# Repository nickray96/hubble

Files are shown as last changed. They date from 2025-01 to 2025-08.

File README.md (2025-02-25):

# hubble
A switched USB hub. 

# Rev 1.0:
* USB 2.0 and USB 3.0
* Tested working (see errata)
* Toggle SW1 to select between host 1 and 2
* Debug connector provides I2C to use via TotalPhase Aardvark (or other debug device)
  * Also routed to USB-C SBU

## Errata
* USB5744 does not enter runtime, looks for I2C host. Remove R14 and R17, puts hub in headless mode.

# Rev 2.0:
* Enable USB5744 port power toggling
* Optionally drive mux sel via Raspberry Pi Pico W (useful for home automation)
* Add DisplayPort mux so I can stop using my monitor OSD (TBD which connectors I'll use)

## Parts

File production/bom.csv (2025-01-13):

Designator | Footprint | Quantity | Value | LCSC Part #
C1, C10, C11, C12, C14, C15, C16, C17, C18, C19, C20, C21, C22, C23, C24, C25, C27, C28, C29, C30, C31, C32, C34, C35, C37, C38, C39, C40, C41, C42, C43, C44, C6, C7, C8, C9 | 0603 | 36 | 0.1uF
C13, C33 | 0603 | 2 | 10uF
C2, C45, C46, C47, C48 | 0603 | 5 | 2.2uF
C26, C36 | 0603 | 2 | 22uF
C3, C4 | 0603 | 2 | 20pF
J1, J2, J5, J6, J7, J8 | USB-TH_XUNPU_USB-301WD-ARY | 6 | USB3_A_LCSC | C2895025
J3 | USB_C_CONN_105450-0101_MOLEX | 1 | USB_C_Receptacle_Molex | C134092
J9 | PinHeader_2x02_P2.54mm_Vertical | 1 | Conn_02x02_Odd_Even
R1 | 0603 | 1 | 330
R10, R13, R14, R17 | 0603 | 4 | 10k
R15 | 0603 | 1 | 11.8k
R16 | 0603 | 1 | 3.74k
R18, R24, R7 | 0603 | 3 | 50k
R19 | 0603 | 1 | 12k
R2, R3 | 0603 | 2 | 5.1k
R20, R21 | 0603 | 2 | 200k
R22 | 0603 | 1 | 12.4k
R23 | 0603 | 1 | 24.9k
R4, R5 | 0603 | 2 | 0
R8 | 0603 | 1 | 100k
SW1 | SW-TH_K3-2235D-F1 | 1 | K3-2235D-F1 | C189615
TP1, TP2, TP3, TP4, TP5, TP6, TP7 | TestPoint_Pad_1.0x1.0mm | 7 | TestPoint
U1 | SOT-143 | 1 | MAX6816EUS+T | C41637
U10, U11, U12, U13, U2, U8, U9 | Texas_DPY0002A_0.6x1mm_P0.65mm | 7 | TPD1E05U06DPY | C2937017
U3 | UQFN-10 | 1 | TS3USB221RSER | C130085
U4, U6 | RGR20_2P05X2P05_TEX | 2 | TPS7A5201QRGRRQ1 | C523802
U5 | VQFN56_2G_MCH | 1 | USB5744 | C633621
U7 | TMLP-18_L2.8-W2.0-P0.40-BL-EP | 1 | FUSB340
Y1 | Crystal_SMD_3225-4Pin_3.2x2.5mm | 1 | X322525MOB4SI | C9006

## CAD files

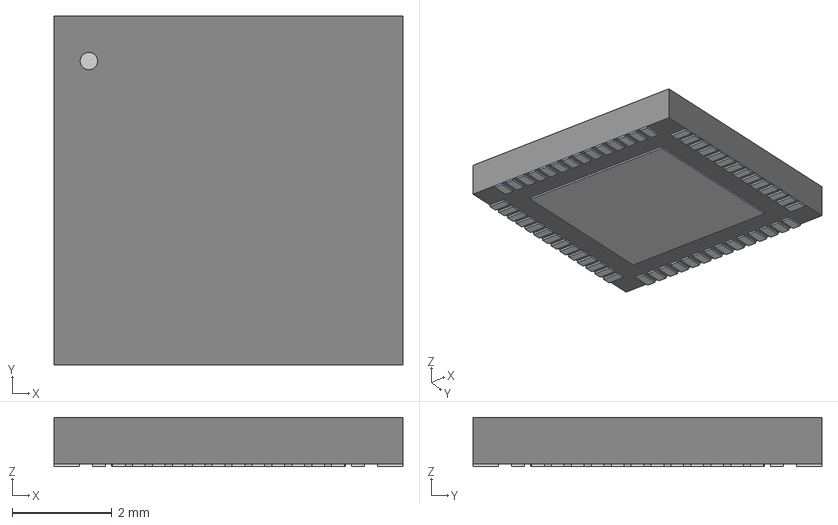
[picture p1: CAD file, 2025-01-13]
3d/VQFN56_2G_MCH.step
7.01 x 7.01 x 0.993 mm

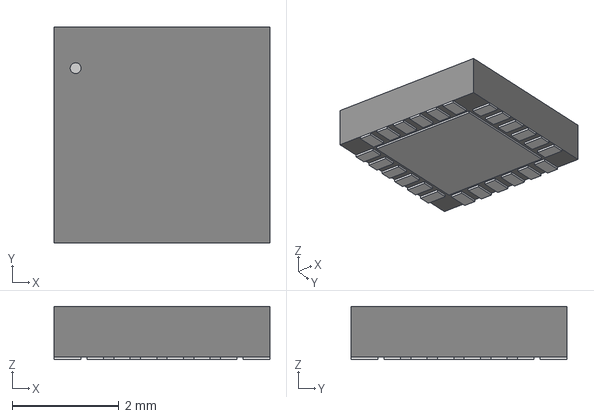
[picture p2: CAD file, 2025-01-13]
3d/QFN24EP_4X4_STM.step
4.04 x 4.04 x 0.993 mm

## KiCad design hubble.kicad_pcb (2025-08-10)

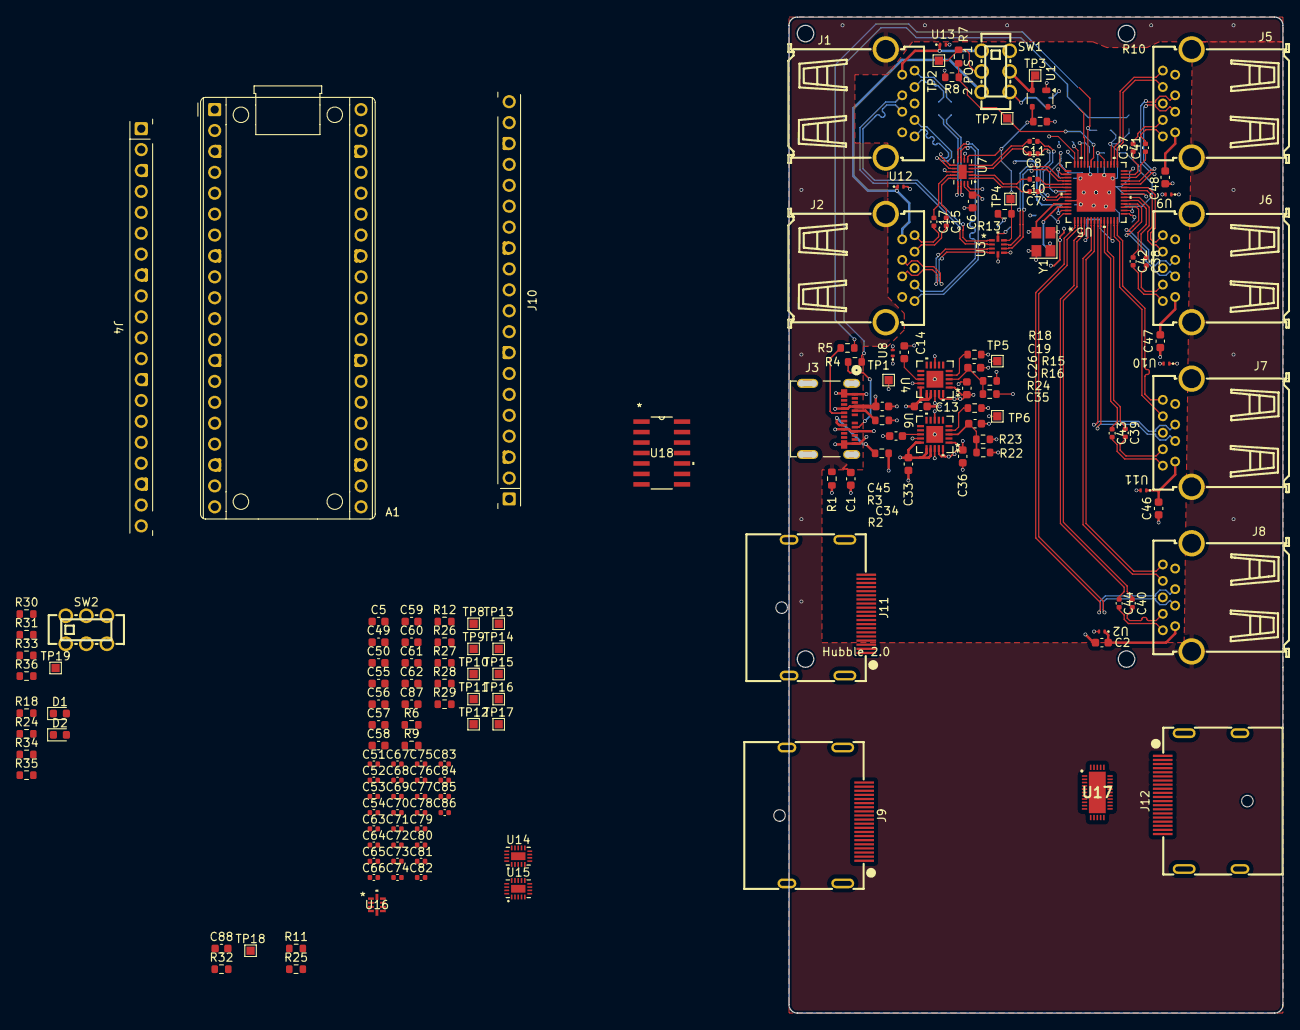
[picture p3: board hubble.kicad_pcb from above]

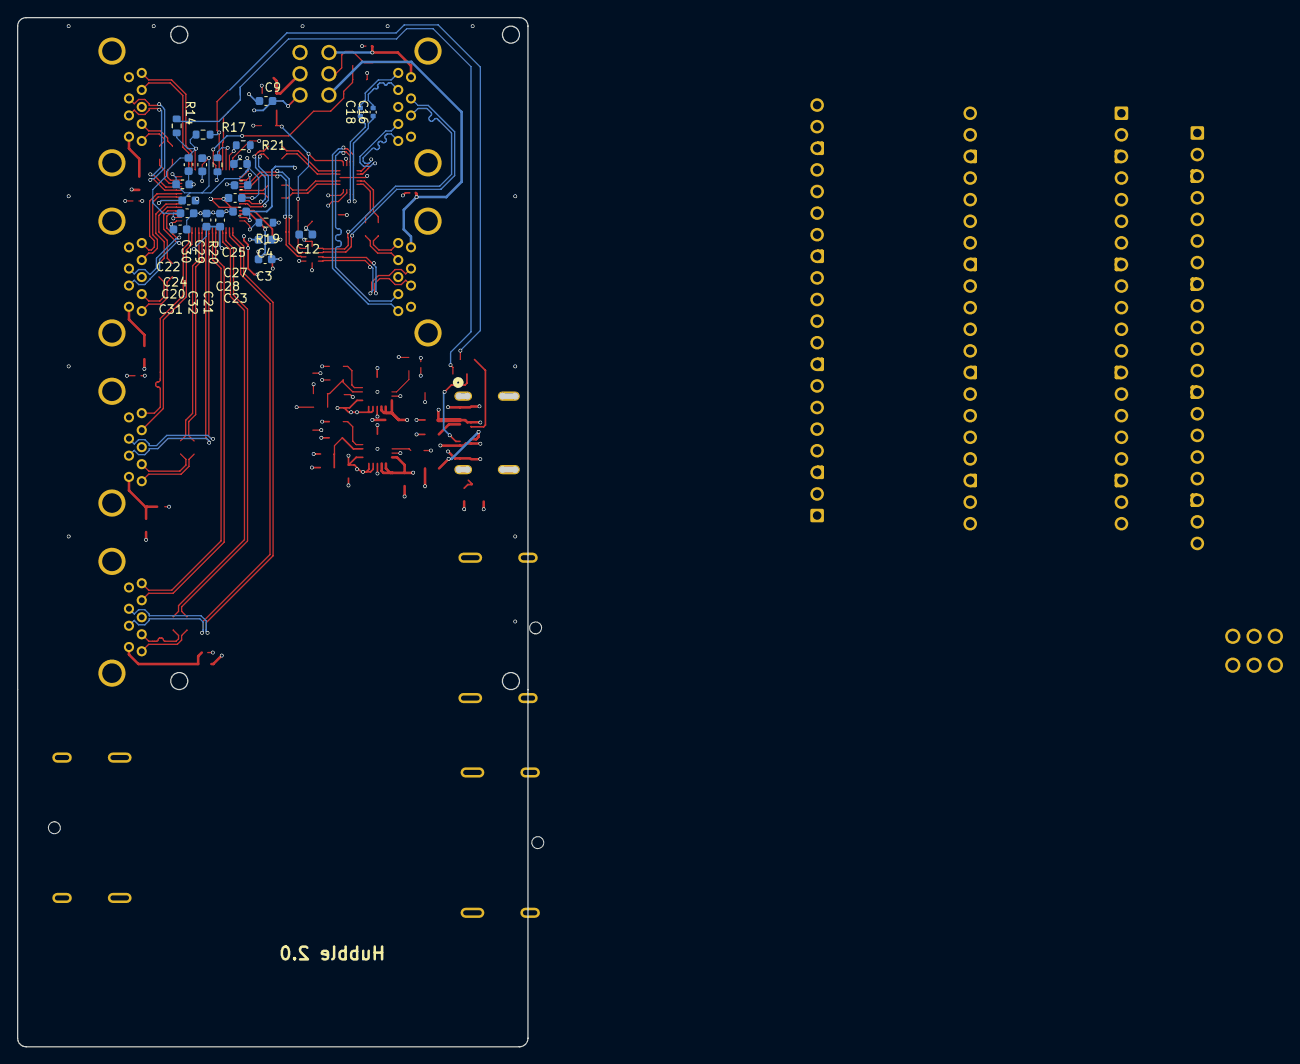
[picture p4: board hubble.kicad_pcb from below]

Board: 4 copper layers, 61.9 x 121.0 mm, 181 parts (23 on the bottom side), 181 nets.

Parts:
A1: RaspberryPi_Pico_W; RaspberryPi_Pico_Common_THT
C1, C5, C6, C9, C12, C14, C19, C20, C21, C22, C23, C24, C25, C27, C28, C29, C30, C31, C32, C34, C35, C49, C50, C55, C56, C57, C58, C59, C60, C61, C87, C88: 0.1uF; C_0603_1608Metric
C2, C45, C46, C47, C48: 2.2uF; C_0603_1608Metric
C3, C4: 20pF; C_0603_1608Metric
C7, C8, C10, C11, C15, C16, C17, C18, C37, C38, C39, C40, C41, C42, C43, C44, C51, C52, C53, C54, C63, C64, C65, C66, C67, C68, C69, C70, C71, C72, C73, C74, C75, C76, C77, C78, C79, C80, C81, C82, C83, C84, C85, C86: 0.1uF; C_0402_1005Metric
C13, C33: 10uF; C_0603_1608Metric
C26, C36: 22uF; C_0603_1608Metric
C62: 4.7uF; C_0603_1608Metric
D1, D2: LED_green; LED_0603_1608Metric
J1, J2, J5, J6, J7, J8: USB3_A_LCSC; USB-TH_XUNPU_USB-301WD-ARY
J3: USB_C_Receptacle_Molex; USB_C_CONN_105450-0101_MOLEX
J4: Pico_Socket_A; RaspberryPi_Pico_PinSocket_1x20_P2.54mm_Vertical
J9, J11, J12: DisplayPort; DISPLAYPORT_XDPF-0205-20S
J10: Pico_Socket_B; RaspberryPi_Pico_PinSocket_1x20_P2.54mm_Vertical
R1, R6, R9, R24#2, R29, R35: 330; R_0603_1608Metric
R2, R3: 5.1k; R_0603_1608Metric
R4, R5, R11, R25: 0; R_0603_1608Metric
R7, R18, R24: 50k; R_0603_1608Metric
R8: 100k; R_0603_1608Metric
R10, R13, R14, R17, R18#2, R26, R27, R30, R32, R34, R36: 10k; R_0603_1608Metric
R12, R28: 1M; R_0603_1608Metric
R15: 11.8k; R_0603_1608Metric
R16: 3.74k; R_0603_1608Metric
R19: 12k; R_0603_1608Metric
R20, R21: 200k; R_0603_1608Metric
R22: 12.4k; R_0603_1608Metric
R23: 24.9k; R_0603_1608Metric
R31, R33: 27; R_0603_1608Metric
SW1, SW2: K3-2235D-F1; SW-TH_K3-2235D-F1
TP1, TP2, TP3, TP4, TP5, TP6, TP7, TP8, TP9, TP10, TP11, TP12, TP13, TP14, TP15, TP16, TP17, TP18, TP19: TestPoint; TestPoint_Pad_1.0x1.0mm
U1: MAX6816EUS+T; SOT-143
U2, U8, U9, U10, U11, U12, U13: TPD1E05U06DPY; Texas_DPY0002A_0.6x1mm_P0.65mm
U3, U16: TS3USB221RSER; UQFN-10
U4, U6: TPS7A5201QRGRRQ1; RGR20_2P05X2P05_TEX
U5: USB5744; VQFN56_2G_MCH
U7, U14, U15: FUSB340; TMLP-18_L2.8-W2.0-P0.40-BL-EP
U17: PI3DPX1203BZLEX; QFN40P300X600X80-33N
U18: SN74CBTLV3126DR; D14
Y1: X322525MOB4SI; Crystal_SMD_3225-4Pin_3.2x2.5mm

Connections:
/DisplayPort/DP_HOST0_AUX_N: C54.2, U16.2 (1D-)
/DisplayPort/DP_HOST0_AUX_P: C51.2, U16.1 (1D+)
/DisplayPort/DP_HOST0_D0_N: C64.1, J9.3 (D0_N)
/DisplayPort/DP_HOST0_D0_P: C63.1, J9.1 (D0_P)
/DisplayPort/DP_HOST0_D1_N: C66.1, J9.6 (D1_N)
/DisplayPort/DP_HOST0_D1_P: C65.1, J9.4 (D1_P)
/DisplayPort/DP_HOST0_D2_N: C68.1, J9.9 (D2_N)
/DisplayPort/DP_HOST0_D2_P: C67.1, J9.7 (D2_P)
/DisplayPort/DP_HOST0_D3_N: C70.1, J9.12 (D3_N)
/DisplayPort/DP_HOST0_D3_P: C69.1, J9.10 (D3_P)
/DisplayPort/DP_HOST0_HPD: J9.18 (HPD), U18.2 (1A)
/DisplayPort/DP_HOST1_AUX_N: C53.2, U16.4 (2D-)
/DisplayPort/DP_HOST1_AUX_P: C52.2, U16.3 (2D+)
/DisplayPort/DP_HOST1_D0_N: C81.1, J11.3 (D0_N)
/DisplayPort/DP_HOST1_D0_P: C79.1, J11.1 (D0_P)
/DisplayPort/DP_HOST1_D1_N: C85.1, J11.6 (D1_N)
/DisplayPort/DP_HOST1_D1_P: C83.1, J11.4 (D1_P)
/DisplayPort/DP_HOST1_D2_N: C82.1, J11.9 (D2_N)
/DisplayPort/DP_HOST1_D2_P: C80.1, J11.7 (D2_P)
/DisplayPort/DP_HOST1_D3_N: C86.1, J11.12 (D3_N)
/DisplayPort/DP_HOST1_D3_P: C84.1, J11.10 (D3_P)
/DisplayPort/DP_HOST1_HPD: J11.18 (HPD), U18.5 (2A)
/DisplayPort/DP_SINK_AUX_N: J12.17 (AUX_N), U16.7 (D-)
/DisplayPort/DP_SINK_AUX_P: J12.15 (AUX_P), U16.8 (D+)
/DisplayPort/DP_SINK_HPD: J12.18 (HPD), U18.3 (1B), U18.6 (2B)
/DisplayPort/I2C_SCL: J4.5 (GPIO3), R5.2, R11.1, R14.2, U17.13 (SCL)
/DisplayPort/I2C_SDA: J4.4 (GPIO2), R4.2, R17.2, R25.1, U17.12 (SDA)
/DisplayPort/MUX_SEL: R10.1, R13.1, TP4.1, U1.3 (OUT), U3.9 (S), U7.6 (S), U14.6 (S), U15.6 (S), U16.9 (S), U18.4 (2OE)
/DisplayPort/~DP_RST: R27.1, U17.29 (FG1/I2C_RESET#)
/DisplayPort/~MUX_SEL: R32.1, TP18.1, U18.1 (1OE)
/Hub/DEVICE_1_USB_N: J8.2 (D-), U5.2 (USB2DN_DM1/PRT_DIS_M1)
/Hub/DEVICE_1_USB_P: J8.3 (D+), U5.1 (USB2DN_DP1/PRT_DIS_P1)
/Hub/DEVICE_2_USB_N: J7.2 (D-), U5.9 (USB2DN_DM2/PRT_DIS_M2)
/Hub/DEVICE_2_USB_P: J7.3 (D+), U5.8 (USB2DN_DP2/PRT_DIS_P2)
/Hub/DEVICE_3_USB_N: J6.2 (D-), U5.18 (USB2DN_DM3/PRT_DIS_M3)
/Hub/DEVICE_3_USB_P: J6.3 (D+), U5.17 (USB2DN_DP3/PRT_DIS_P3)
/Hub/DEVICE_4_USB_N: J5.2 (D-), U5.25 (USB2DN_DM4/PRT_DIS_M4)
/Hub/DEVICE_4_USB_P: J5.3 (D+), U5.24 (USB2DN_DP4/PRT_DIS_P4)
/Hub/HOST_1_USB_N: J1.2 (D-), U3.2 (1D-)
/Hub/HOST_1_USB_P: J1.3 (D+), U3.1 (1D+)
/Hub/HOST_2_USB_N: J2.2 (D-), U3.4 (2D-)
/Hub/HOST_2_USB_P: J2.3 (D+), U3.3 (2D+)
/Hub/HUB_USB_N: U3.7 (D-), U5.46 (USB2UP_DM)
/Hub/HUB_USB_P: U3.8 (D+), U5.45 (USB2UP_DP)
/Hub/SS_RX_DEVICE_1_N: J8.5 (SSRX-), U5.7 (USB3DN_RXDM1)
/Hub/SS_RX_DEVICE_1_P: J8.6 (SSRX+), U5.6 (USB3DN_RXDP1)
/Hub/SS_RX_DEVICE_2_N: J7.5 (SSRX-), U5.14 (USB3DN_RXDM2)
/Hub/SS_RX_DEVICE_2_P: J7.6 (SSRX+), U5.13 (USB3DN_RXDP2)
/Hub/SS_RX_DEVICE_3_N: J6.5 (SSRX-), U5.23 (USB3DN_RXDM3)
/Hub/SS_RX_DEVICE_3_P: J6.6 (SSRX+), U5.22 (USB3DN_RXDP3)
/Hub/SS_RX_DEVICE_4_N: J5.5 (SSRX-), U5.30 (USB3DN_RXDM4)
/Hub/SS_RX_DEVICE_4_P: J5.6 (SSRX+), U5.29 (USB3DN_RXDP4)
/Hub/SS_RX_HOST_1_N: J1.5 (SSRX-), U7.10 (SSRX1+)
/Hub/SS_RX_HOST_1_P: J1.6 (SSRX+), U7.11 (SSRX1-)
/Hub/SS_RX_HOST_2_N: J2.5 (SSRX-), U7.9 (SSRX2-)
/Hub/SS_RX_HOST_2_P: J2.6 (SSRX+), U7.8 (SSRX2+)
/Hub/SS_RX_HUB_CAP_N: C8.1, U7.4 (SSRXCOM-)
/Hub/SS_RX_HUB_CAP_P: C7.1, U7.5 (SSRXCOM+)
/Hub/SS_RX_HUB_N: C8.2, U5.51 (USB3UP_RXDM)
/Hub/SS_RX_HUB_P: C7.2, U5.50 (USB3UP_RXDP)
/Hub/SS_TX_DEVICE_1_CAP_N: C40.1, U5.4 (USB3DN_TXDM1)
/Hub/SS_TX_DEVICE_1_CAP_P: C44.1, U5.3 (USB3DN_TXDP1)
/Hub/SS_TX_DEVICE_1_N: C40.2, J8.8 (SSTX-)
/Hub/SS_TX_DEVICE_1_P: C44.2, J8.9 (SSTX+)
/Hub/SS_TX_DEVICE_2_CAP_N: C39.1, U5.11 (USB3DN_TXDM2)
/Hub/SS_TX_DEVICE_2_CAP_P: C43.1, U5.10 (USB3DN_TXDP2)
/Hub/SS_TX_DEVICE_2_N: C39.2, J7.8 (SSTX-)
/Hub/SS_TX_DEVICE_2_P: C43.2, J7.9 (SSTX+)
/Hub/SS_TX_DEVICE_3_CAP_N: C38.1, U5.20 (USB3DN_TXDM3)
/Hub/SS_TX_DEVICE_3_CAP_P: C42.1, U5.19 (USB3DN_TXDP3)
/Hub/SS_TX_DEVICE_3_N: C38.2, J6.8 (SSTX-)
/Hub/SS_TX_DEVICE_3_P: C42.2, J6.9 (SSTX+)
/Hub/SS_TX_DEVICE_4_CAP_N: C37.1, U5.27 (USB3DN_TXDM4)
/Hub/SS_TX_DEVICE_4_CAP_P: C41.1, U5.26 (USB3DN_TXDP4)
/Hub/SS_TX_DEVICE_4_N: C37.2, J5.8 (SSTX-)
/Hub/SS_TX_DEVICE_4_P: C41.2, J5.9 (SSTX+)
/Hub/SS_TX_HOST_1_CAP_N: C16.2, U7.15 (SSTX1+)
/Hub/SS_TX_HOST_1_CAP_P: C15.2, U7.16 (SSTX1-)
/Hub/SS_TX_HOST_1_N: C16.1, J1.8 (SSTX-)
/Hub/SS_TX_HOST_1_P: C15.1, J1.9 (SSTX+)
/Hub/SS_TX_HOST_2_CAP_N: C17.2, U7.14 (SSTX2-)
/Hub/SS_TX_HOST_2_CAP_P: C18.2, U7.13 (SSTX2+)
/Hub/SS_TX_HOST_2_N: C17.1, J2.8 (SSTX-)
/Hub/SS_TX_HOST_2_P: C18.1, J2.9 (SSTX+)
/Hub/SS_TX_HUB_CAP_N: C11.1, U7.1 (SSTXCOM-)
/Hub/SS_TX_HUB_CAP_P: C10.1, U7.2 (SSTXCOM+)
/Hub/SS_TX_HUB_N: C11.2, U5.48 (USB3UP_TXDM)
/Hub/SS_TX_HUB_P: C10.2, U5.47 (USB3UP_TXDP)
/Hub/VBUS_DET: R7.2, R8.1, TP7.1, U5.37 (VBUS_DET)
/Hub/VBUS_DET_1: J1.1 (VBUS), SW1.4 (A), U13.1 (I/O)
/Hub/VBUS_DET_2: J2.1 (VBUS), SW1.6 (C), U12.1 (I/O)
/MCU/MUX_SEL_MANUAL: SW1.2 (B), SW2.1 (A)
/MCU/MUX_SEL_MCU: J4.1 (GPIO0), R30.1, SW2.3 (C)
/MCU/PI_RUN: J10.10 (RUN), SW2.5 (B)
/Power/MCU_USB_DN: J3.A7 (D-), J3.B7 (D-)
/Power/MCU_USB_DP: J3.A6 (D+), J3.B6 (D+)
GND: C1.1, C2.1, C3.1, C4.1, C5.1, C6.1, C9.1, C12.1, C13.1, C14.1, C20.2, C21.2, C22.2, C23.2, C24.2, C25.2, C26.1, C27.2, C28.2, C29.2, C30.2, C31.2, C32.2, C33.1, C34.1, C36.1, C45.1, C46.1, C47.1, C48.1, C49.1, C50.1, C55.1, C56.1, C57.1, C58.2, C59.2, C60.2, C61.2, C62.2, C87.1, C88.1, J1.4 (GND), J1.7 (DRAIN), J2.4 (GND), J2.7 (DRAIN), J3.A1 (GND), J3.A12 (GND), J3.B1 (GND), J3.B12 (GND), J4.3 (GND), J4.8 (GND), J4.13 (GND), J4.18 (GND), J5.4 (GND), J5.7 (DRAIN), J6.4 (GND), J6.7 (DRAIN), J7.4 (GND), J7.7 (DRAIN), J8.4 (GND), J8.7 (DRAIN), J9.2 (GND), J9.5 (GND), J9.8 (GND), J9.11 (GND), J9.16 (GND), J10.3 (GND), J10.8 (GND), J10.13 (AGND), J10.18 (GND), J11.2 (GND), J11.5 (GND), J11.8 (GND), J11.11 (GND), J11.16 (GND), J12.19 (DP_PWR_RET), R1.2, R2.2, R3.2, R6.2, R8.2, R9.2, R10.2, R12.2, R13.2, R16.2, R19.1, R20.2, R21.2, R23.2, R24#2.2, R27.2, R28.2, R29.2, R30.2, R32.2, R35.2, SW1.1 (A), SW2.4 (A), U1.1 (GND), U2.2 (GND), U3.5 (GND), U3.6 (*OE), U4.8 (GND), U4.18 (GND), U4.21 (EPAD), U5.52 (ATEST), U5.57 (PAD), U6.8 (GND), U6.18 (GND), U6.21 (EPAD), U7.3 (GND), U7.7 (OE#), U7.12 (GND), U7.18 (GND), U7.19 (GND), U8.2 (GND), U9.2 (GND), U10.2 (GND), U11.2 (GND), U12.2 (GND), U13.2 (GND), U14.3 (GND), U14.7 (OE#), U14.12 (GND), U14.18 (GND), U14.19 (GND), U15.3 (GND), U15.7 (OE#), U15.12 (GND), U15.18 (GND), U15.19 (GND), U16.5 (GND), U16.6 (*OE), U17.14 (PRSNT#), U17.33 (GND), U18.7 (GND), Y1.2, Y1.4
unnamed: A1.3 (GND), A1.8 (GND), A1.13 (GND), A1.18 (GND), A1.23 (GND), A1.28 (GND), A1.38 (GND)
unnamed: D1.2 (A), R34.2, U6.4 (PG)
unnamed: D1.1 (K), R24#2.1
unnamed: D2.2 (A), R18#2.2, U4.4 (PG)
unnamed: D2.1 (K), R35.1
unnamed: J3.A5 (CC1), R3.1
unnamed: J3.B5 (CC2), R2.1
unnamed: J3.A8 (SBU1), R4.1
unnamed: J3.B8 (SBU2), R5.1
unnamed: C54.1, J9.17 (AUX_N)
unnamed: C51.1, J9.15 (AUX_P)
unnamed: J9.13 (CFG1), TP13.1
unnamed: J9.14 (CFG2), TP14.1
unnamed: C53.1, J11.17 (AUX_N)
unnamed: C52.1, J11.15 (AUX_P)
unnamed: J11.13 (CFG1), TP11.1
unnamed: J11.14 (CFG2), TP12.1
unnamed: J12.13 (CFG1), R28.1
unnamed: J12.14 (CFG2), R12.1
unnamed: C73.2, J12.3 (D0_N)
unnamed: C71.2, J12.1 (D0_P)
unnamed: C77.2, J12.6 (D1_N)
unnamed: C75.2, J12.4 (D1_P)
unnamed: C74.2, J12.9 (D2_N)
unnamed: C72.2, J12.7 (D2_P)
unnamed: C78.2, J12.12 (D3_N)
unnamed: C76.2, J12.10 (D3_P)
unnamed: R7.1, SW1.5 (B), TP2.1
unnamed: R36.2, SW2.6 (C)
unnamed: SW2.2 (B), TP3.1, U1.2 (IN)
unnamed: C19.1, R15.2, R16.1, U4.3 (FB)
unnamed: C14.2, U4.13 (NR/SS)
unnamed: R19.2, U5.56 (RBIAS)
unnamed: R21.1, U5.41 (SPI_CE_N/CFG_NON_REM)
unnamed: R11.2, U5.38 (SPI_CLK/SMCLK)
unnamed: R20.1, U5.40 (SPI_DI/CFG_BC_EN)
unnamed: R25.2, U5.39 (SPI_DO/SMDAT)
unnamed: C3.2, U5.54 (XTALI/CLK_IN), Y1.1
unnamed: C4.2, U5.53 (XTALO), Y1.3
unnamed: C35.1, R22.2, R23.1, U6.3 (FB)
unnamed: C34.2, U6.13 (NR/SS)
unnamed: C65.2, U14.10 (SSRX1+)
unnamed: C66.2, U14.11 (SSRX1-)
unnamed: C83.2, U14.8 (SSRX2+)
unnamed: C85.2, U14.9 (SSRX2-)
unnamed: U14.5 (SSRXCOM+), U17.4 (A1RX+)
unnamed: U14.4 (SSRXCOM-), U17.5 (A1RX-)
unnamed: C63.2, U14.15 (SSTX1+)
unnamed: C64.2, U14.16 (SSTX1-)
unnamed: C79.2, U14.13 (SSTX2+)
unnamed: C81.2, U14.14 (SSTX2-)
unnamed: U14.2 (SSTXCOM+), U17.1 (A0RX+)
unnamed: U14.1 (SSTXCOM-), U17.2 (A0RX-)
unnamed: C69.2, U15.10 (SSRX1+)
unnamed: C70.2, U15.11 (SSRX1-)
unnamed: C84.2, U15.8 (SSRX2+)
unnamed: C86.2, U15.9 (SSRX2-)
unnamed: U15.5 (SSRXCOM+), U17.10 (A3RX+)
unnamed: U15.4 (SSRXCOM-), U17.11 (A3RX-)
unnamed: C67.2, U15.15 (SSTX1+)
unnamed: C68.2, U15.16 (SSTX1-)
unnamed: C80.2, U15.13 (SSTX2+)
unnamed: C82.2, U15.14 (SSTX2-)
unnamed: U15.2 (SSTXCOM+), U17.7 (A2RX+)
unnamed: U15.1 (SSTXCOM-), U17.8 (A2RX-)
unnamed: C73.1, U17.27 (A0TX+)
unnamed: C71.1, U17.26 (A0TX-)
unnamed: C77.1, U17.24 (A1TX+)
unnamed: C75.1, U17.23 (A1TX-)
unnamed: C74.1, U17.21 (A2TX+)
unnamed: C72.1, U17.20 (A2TX-)
unnamed: C78.1, U17.18 (A3TX+)
unnamed: C76.1, U17.17 (A3TX-)
unnamed: R26.2, U17.15 (ENI2C)
unnamed: TP16.1, U18.9 (3A)
unnamed: TP17.1, U18.8 (3B)
unnamed: TP15.1, U18.10 (3OE)
unnamed: TP9.1, U18.12 (4A)
unnamed: TP10.1, U18.11 (4B)
unnamed: TP8.1, U18.13 (4OE)
Shield: C1.2, C5.2, C49.2, C55.2, J1.10 (SHIELD), J2.10 (SHIELD), J5.10 (SHIELD), J6.10 (SHIELD), J7.10 (SHIELD), J8.10 (SHIELD), J12.2 (GND), J12.5 (GND), J12.8 (GND), J12.11 (GND), J12.16 (GND), R1.1, R6.1, R9.1, R29.1
VBUS_IN: C2.2, C13.2, C33.2, C45.2, C46.2, C47.2, C48.2, J3.A4 (VBUS), J3.A9 (VBUS), J3.B4 (VBUS), J3.B9 (VBUS), J5.1 (VBUS), J6.1 (VBUS), J7.1 (VBUS), J8.1 (VBUS), J10.19 (VSYS), J10.20 (VBUS), TP1.1, U2.1 (I/O), U4.14 (EN), U4.15 (IN), U4.16 (IN), U4.17 (IN), U6.14 (EN), U6.15 (IN), U6.16 (IN), U6.17 (IN), U8.1 (I/O), U9.1 (I/O), U10.1 (I/O), U11.1 (I/O)
VCC_1.2V: C21.1, C22.1, C24.1, C25.1, C28.1, C29.1, C31.1, C32.1, C35.2, C36.2, R22.1, R24.1, TP6.1, U5.5 (VDD12), U5.12 (VDD12), U5.15 (VDD12), U5.21 (VDD12), U5.28 (VDD12), U5.33 (VDD12), U5.43 (VDD12), U5.49 (VDD12), U6.1 (OUT), U6.19 (OUT), U6.20 (OUT)
VCC_3.3V: C6.2, C9.2, C12.2, C19.2, C20.1, C23.1, C26.2, C27.1, C30.1, C50.2, C56.2, C57.2, C58.1, C59.1, C60.1, C61.1, C62.1, C87.2, C88.2, J12.20 (DP_PWR), R14.1, R15.1, R17.1, R18.1, R18#2.1, R26.1, R34.1, R36.1, SW1.3 (C), TP5.1, U1.4 (VCC), U3.10 (VCC), U4.1 (OUT), U4.19 (OUT), U4.20 (OUT), U5.16 (VDD33), U5.31 (VDD33), U5.42 (RESET_N), U5.44 (VDD33), U5.55 (VDD33), U7.17 (VDD), U14.17 (VDD), U15.17 (VDD), U16.10 (VCC), U17.3 (VDD), U17.6 (VDD_2), U17.9 (VDD_3), U17.19 (VDD_4), U17.22 (VDD_5), U17.25 (VDD_6), U17.28 (FG0), U17.30 (EQ1/AD1), U17.31 (EQ2/AD2), U17.32 (EQ3/AD3), U18.14 (VCC)

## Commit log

2025-01-13 Add Rev 1.0 files
    [QFN24EP_4X4_STM.step, VQFN56_2G_MCH.step, bom.csv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]
2025-02-25 Add ki-lime-pi-to-go submodule, upgrade to KiCad 9, put a Pico W and through hole header on the schematic
    [hubble.kicad_pcb, hubble.kicad_sch]
2025-03-31 Add 2:1 displayport mux using TS3DV642
    [hubble.kicad_sch]
2025-08-09 Use 2x FUSB340 mux for DisplayPort, break up schematic into hierarchical pages
    [displayport.kicad_sch, hub.kicad_sch, hubble.kicad_sch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]
2025-08-09 Add PI3DPX1203BZLEX DisplayPort redriver and start adding it to schematic
    [displayport.kicad_sch, hub.kicad_sch, mcu.kicad_sch]
2025-08-09 Change all high-speed decoupling caps to 0402s
    [displayport.kicad_sch, hub.kicad_sch]
2025-08-10 Wiring up DisplayPort HPD signals
    [displayport.kicad_sch, mcu.kicad_sch]
2025-08-10 Start wiring up Pi Pico
    [hubble.kicad_pcb, hubble.kicad_sch, mcu.kicad_sch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]
2025-08-10 Wire up more of the Pico
    [displayport.kicad_sch, hub.kicad_sch, hubble.kicad_pcb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]
